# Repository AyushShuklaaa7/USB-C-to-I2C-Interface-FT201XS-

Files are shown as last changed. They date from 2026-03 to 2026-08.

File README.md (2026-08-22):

Overview

This project converts USB communication to I2C using the FT201XS, making it useful for testing, debugging, or interfacing with I2C-based sensors and modules.
The board is powered via USB-C and includes an onboard LDO to generate a stable 3.3V supply, which is used for both the IC and I2C communication.

## Preview

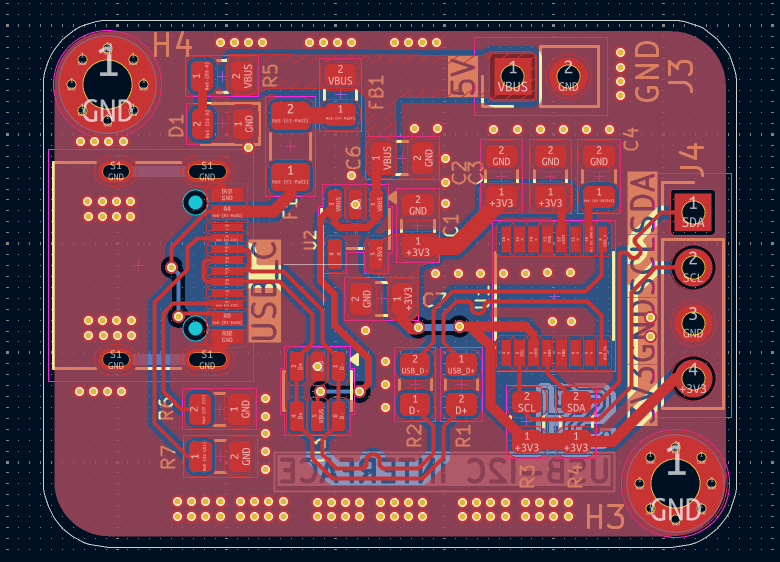
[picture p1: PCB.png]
PCB

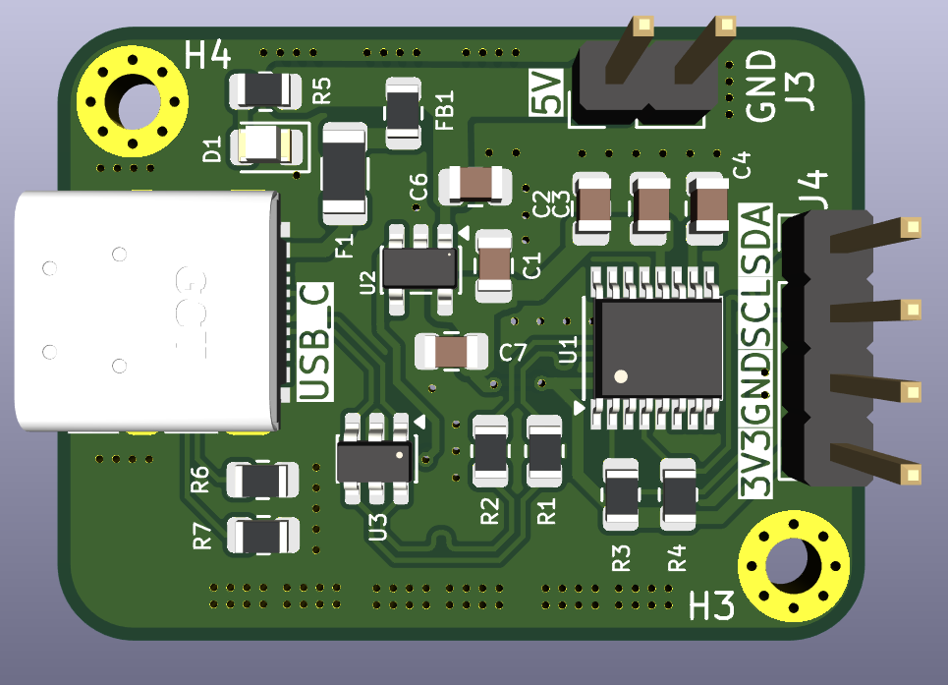
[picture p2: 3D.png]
3D View

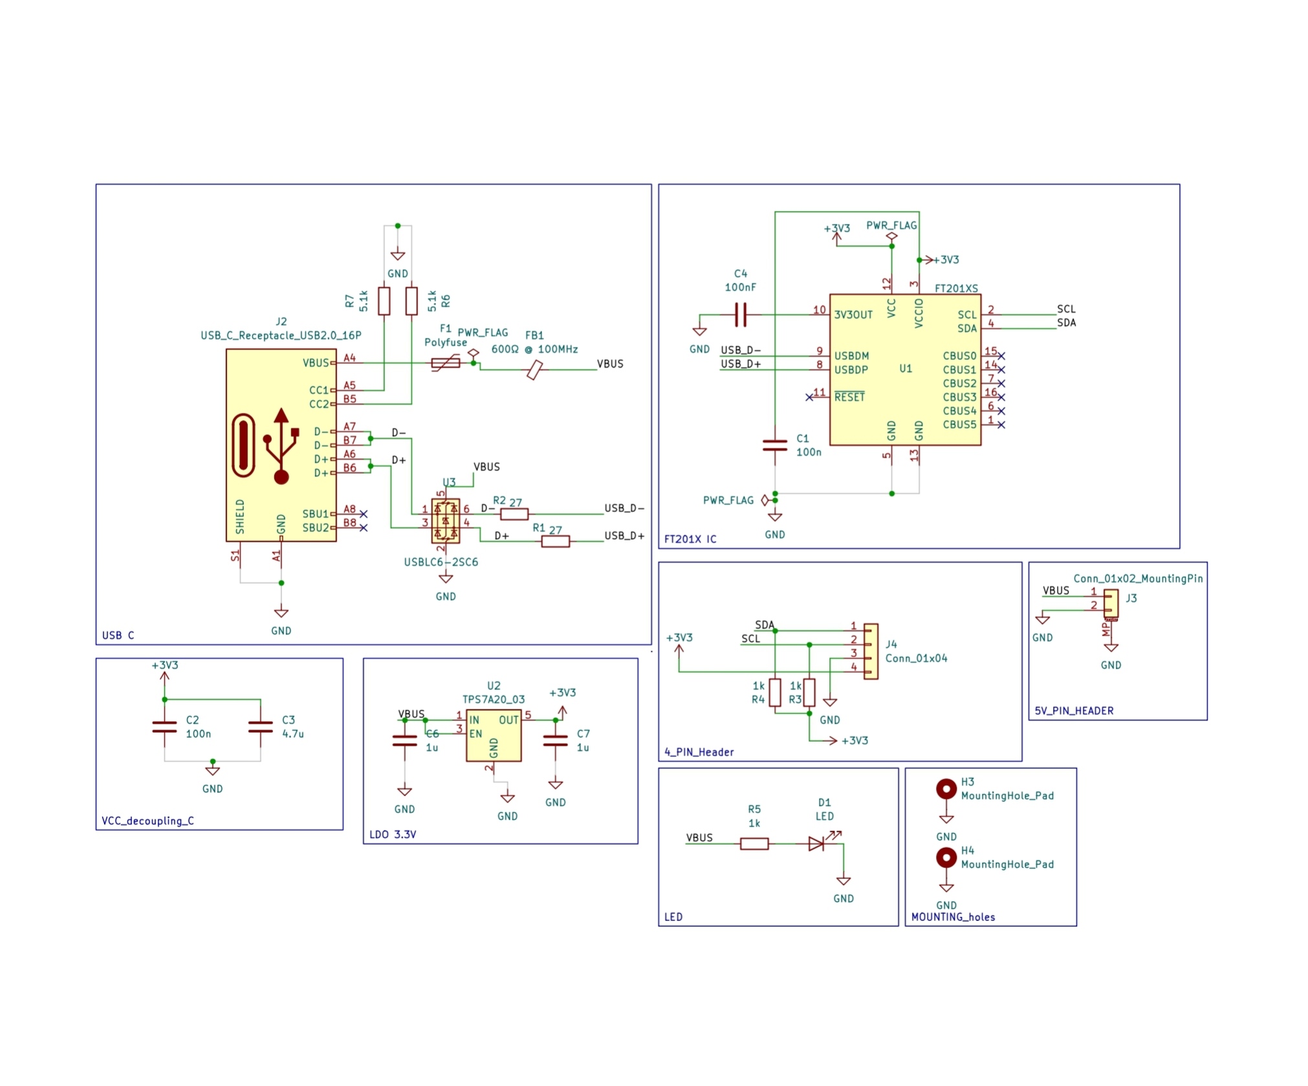
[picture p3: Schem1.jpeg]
Schematic


⚙️Key Components

1. FT201XS (USB to I2C Bridge)
2. TPS7A20_03 (3.3V LDO)
3. USB-C Connector
4. Power Indicator LED

🧠 Design Approach & Working

* This board is designed to provide a simple bridge between USB and I2C communication using the FT201XS IC.
* the USB D+/D- differential pairs are routed with matched lengths and kept short to ensure error-free USB Full-Speed communication.
* When the board is connected via USB-C, the 5V (VBUS) from the USB is used as the primary power source. This 5V is passed through a polyfuse for overcurrent protection and then filtered using a ferrite bead to reduce high-frequency noise. A power indicator LED is connected to VBUS to show when the board is powered.
* The 5V input is then regulated down to 3.3V using an onboard LDO. This 3.3V supply powers the FT201XS IC,The FT201XS acts as a USB-to-I2C bridge.
* It communicates with the host computer over USB and converts those signals into I2C signals (SDA and SCL), which are exposed through the output header.
* For flexibility, both 3.3V (regulated) and 5V (VBUS) are exposed on the output header. While 5V can be used to power external modules, the I2C communication itself is strictly limited to 3.3V logic levels.
* Additional protection is included using an ESD protection device on the USB data lines (D+ and D−) to safeguard the board from electrostatic discharge events.

Tools Used 
KiCad (for schematic and PCB design)

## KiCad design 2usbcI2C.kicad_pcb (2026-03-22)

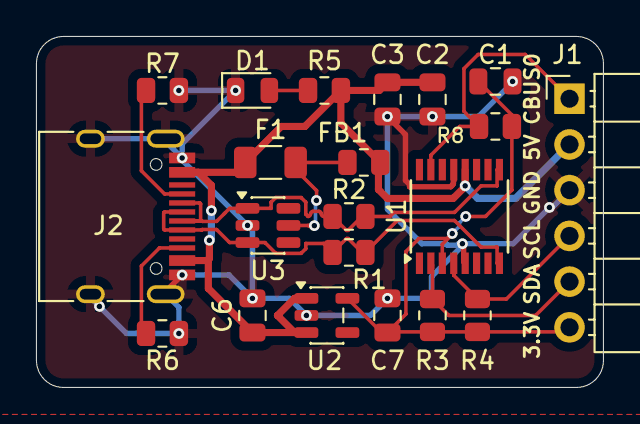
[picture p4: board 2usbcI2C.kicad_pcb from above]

Board: 2 copper layers, 31.5 x 19.5 mm, 21 parts (0 on the bottom side), 12 nets.

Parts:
C1, C2: 100n; C_0805_2012Metric
C3: 4.7u; C_0805_2012Metric
C6, C7: 1u; C_0805_2012Metric
D1: LED; LED_0805_2012Metric
F1: Polyfuse; Fuse_1206_3216Metric
FB1: 600Ω @ 100MHz; R_0805_2012Metric
J1: Conn_01x06_MountingPin; PinHeader_1x06_P2.54mm_Horizontal
J2: USB_C_Receptacle_USB2.0_16P; USB_C_Receptacle_HRO_TYPE-C-31-M-12
R1, R2: 27; R_0805_2012Metric
R3, R4, R5, R8: 1k; R_0805_2012Metric
R6, R7: 5.1k; R_0805_2012Metric
U1: FT201XS; SSOP-16_3.9x4.9mm_P0.635mm
U2: TLV71333PDBV; SOT-23-5
U3: USBLC6-2SC6; SOT-23-6

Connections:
/CBUS0: J1.1, R8.2, U1.15 (CBUS0)
/D+: J2.A6 (D+), J2.B6 (D+), R1.1, R1.2, U1.8 (USBDP), U3.3 (I/O2)
/D-: J2.A7 (D-), J2.B7 (D-), R2.1, R2.2, U1.9 (USBDM), U3.1 (I/O1)
/SCL: J1.5, R3.2, U1.2 (SCL)
/SDA: J1.4, R4.2, U1.4 (SDA)
/VBUS: C2.1, C3.1, C6.1, F1.1, FB1.2, J1.2, J2.A4 (VBUS), J2.A9 (VBUS), J2.B4 (VBUS), J2.B9 (VBUS), R5.2, U1.12 (VCC), U2.1 (IN), U2.3 (EN)
/VCCIO: C1.1, C7.1, J1.6, R3.1, R4.1, R8.1, U1.3 (VCCIO), U2.5 (OUT)
GND: C1.2, C2.2, C3.2, C6.2, C7.2, D1.1 (K), J1.3, J2.A1 (GND), J2.A12 (GND), J2.B1 (GND), J2.B12 (GND), J2.S1 (SHIELD), R6.1, R7.2, U1.5 (GND), U1.13 (GND), U2.2 (GND), U3.2 (GND)
unnamed: D1.2 (A), R5.1
unnamed: J2.A5 (CC1), R7.1
unnamed: J2.B5 (CC2), R6.2
unnamed: F1.2, FB1.1, U3.5 (VBUS)

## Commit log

2026-08-02 Rename Screenshot 2026-08-02 144037.png to PCB.png
2026-08-22 Update schematic image format from PNG to JPEG
